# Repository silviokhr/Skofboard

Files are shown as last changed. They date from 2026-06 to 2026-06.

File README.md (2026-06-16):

# Split Ergonomic Wireless Gasket-Mounted Keyboard

<div align="center">
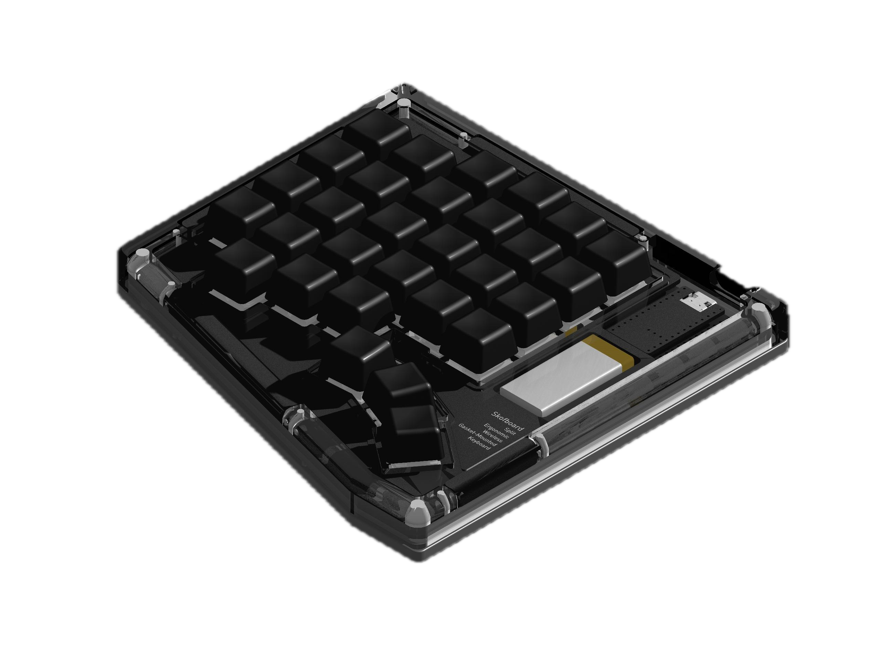
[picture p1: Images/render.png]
Split Ergonomic Keyboard
  
</div>

## Features

- **Ergonomic split design** — reduces wrist strain and promotes a more neutral typing position
- **Ortholinear layout**     — aligns keys in a grid, reducing finger travel distance with 3 dedicated thumb buttons
- **Gasket-mounted PCB**     — provides a dampened sound profile and soft keystroke feel
- **Magnetic closure**       — enables quick assembly and disassembly without tools
- **Reversible PCB design**  — single PCB works for both left and right halves
- **Hot-swappable switches** — easily swap or customize switches without soldering
- **ZMK firmware support**   — fully customizable keymap via ZMK Studio
- **Wireless connectivity**  — powered by the nice!nano v2.0 microcontroller

---

## Case

All case parts are CNC machined, and material selection significantly impacts the sound profile. The rigid aluminum base dampens resonance while the polycarbonate top provides acoustic transparency, and rounded internal surfaces minimize harsh reflections for a refined keystroke sound. STL files are included for 3D-printed case variants.

| Part | Material | Surface Finish |
|---|---|---|
| Top casing | Polycarbonate (PC) | Blue-tinted vapor polishing |
| Bottom casing | Aluminum 6061 | Bead blasting + anodizing |

---

## Parts List (Bill of Materials)

Quantities are **per half** — a complete keyboard requires two of everything below.

| Qty | Component | Specification |
|-----|---|---|
| 8 | Corner magnet | Neodymium disc, ⌀4 × 3 mm |
| 16 | Edge magnet | Neodymium disc, ⌀2 × 3 mm |
| 6 | Large gasket foam | Poron, 4.5 × 7 × 2 mm |
| 2 | Small gasket foam | Poron, 4.5 × 4 × 2 mm |
| 4 | Rubber foot | ⌀8 × 1.6 mm |
| 1 | Microcontroller | nice!nano v2.0 |
| 2 | Microcontroller socket 12-pin | Mill Max 315-43-112-41-003000 |
| 24 | Socket pins | Mill Max 3320-0-00-15-00-00-03-0 |
| 1 | Battery | 3.7 V LiPo, 250 mAh, model 502030, 2P-PH connector |
| 1 | Battery connector | S2B-PH-K-S(LF)(SN) |
| 1 | Power switch | MSK12C02 (SMD slide switch) |
| 30 | Keyswitch | MX-format (any compatible switch) |
| 30 | Hotswap socket | Kailh MX-format |
| 30 | Diode | 1N4148W, SOD-123 |

### Part Notes

Only the parts below have constraints or behavior worth calling out; everything else fits as listed.

- **Magnets** — Cutouts are intentionally oversized to ensure a proper fit during assembly. Corner cutouts are ⌀4.1 mm × 3 mm deep; edge cutouts are ⌀2.1 mm × 3 mm deep.
- **Rubber feet** — Seat into ⌀8 mm × 1.5 mm-deep cutouts and must protrude a minimum of 0.1 mm below the case bottom for optimal grip.
- **Battery** — The cutout on the top plate is shared with the battery connector jack, which limits usable space. Optimal dimensions are **50 mm (H) × 20 mm (W) × 30 mm (D)**. ⚠️ Taller batteries are possible, but wider or longer batteries are not recommended and may not fit reliably.

---

## PCB Specifications

- **Layer count:** 2-layer
- **Material:** FR-4, 1.6 mm thickness
- **Copper weight:** 1 oz
- **Surface finish:** LeadFree HASL

**Design note:** The PCB switchplate (`SkofTopPlate.kicad_pcb`) is 1.6 mm FR-4 (standard manufacturing thickness), while standard MX switches are designed for 1.5 mm plates. Because of this 0.1 mm difference, switches fit securely but may feel slightly tight.

---

## Keymap

The default keymap is currently a placeholder and varies by region. To customize it, press the **`studio_unlock`** key on the left half — at **column 1, row 2** — to enter configuration mode in ZMK Studio.

---

## Assembly Guide

> Build is **per half** — repeat all steps for both. The PCB is reversible, so each half is configured by solder jumpers (step 3) before anything is populated.

**Case prep**

1. **Attach the feet** to the bottom casing.
2. **Glue in the magnets** (corner and edge) into their cutouts. ⚠️ Check polarity *before* gluing — all magnets must be oriented so the top and bottom casings attract when closed. (See Part Notes for fit.)

**PCB**

3. **Set the handedness** — close the solder-jumper bridges that configure the PCB for the left or right half (per the build files), **before** soldering any sockets:
   - **Microcontroller** jumpers — front (top) side
   - **Battery** jumpers — back (bottom) side
4. **Populate the PCB** — on the **back**, solder the diodes and hotswap sockets; on the **front**, solder the power switch, battery connector, and microcontroller sockets.
5. **Mount the nice!nano v2.0** — seat the header pins in the sockets, then mount the controller **face-down (component side against the PCB, bare back facing up)** and solder the pins so it stays removable.

**Power test** *(before switches — easier to fix solder issues now)*

6. **Connect the battery** with the power switch **off**, checking polarity.
7. **Flash and test** — flash the firmware (double-tap reset for the bootloader), power on, and confirm the half boots, pairs with the other half, and connects to your host.

**Plate + switches**

8. **Add the gasket foam** — place the foam strips in their positions per the build files.
9. **Install switches** — straighten any bent pins, fit 3–4 corner switches first to align the plate, then drop in the rest through the switchplate.

**Finish**

10. **Final check** — verify every key registers.
11. **Close the case** — join the top and bottom casings via the magnetic closure.

---

## Credits

This project uses open-source hardware footprints licensed under MIT and CC-BY-NC-SA 4.0 by Marco Massarelli (@ceoloide) and contributors.

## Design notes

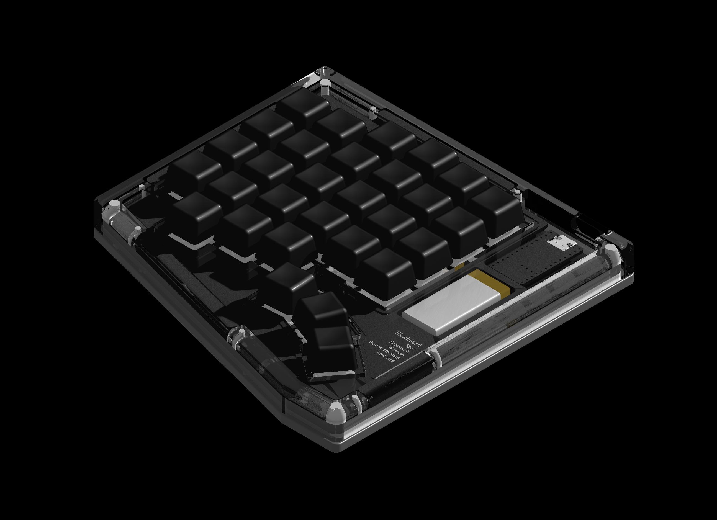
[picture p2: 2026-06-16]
Images/render.jpeg

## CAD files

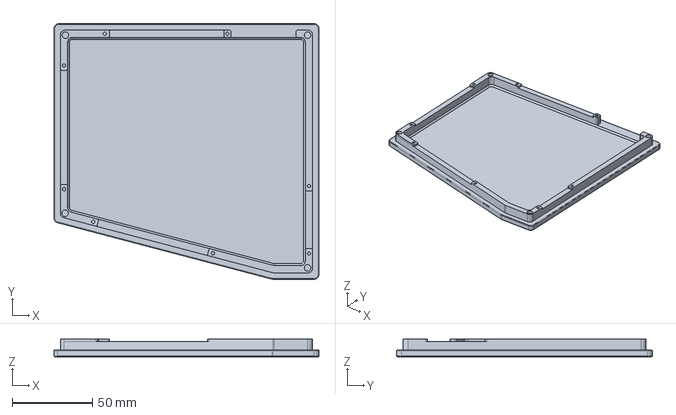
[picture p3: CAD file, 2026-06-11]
Case/Left/Bottom/BB6_BOT_L.stp
164.9 x 159.0 x 10.9 mm

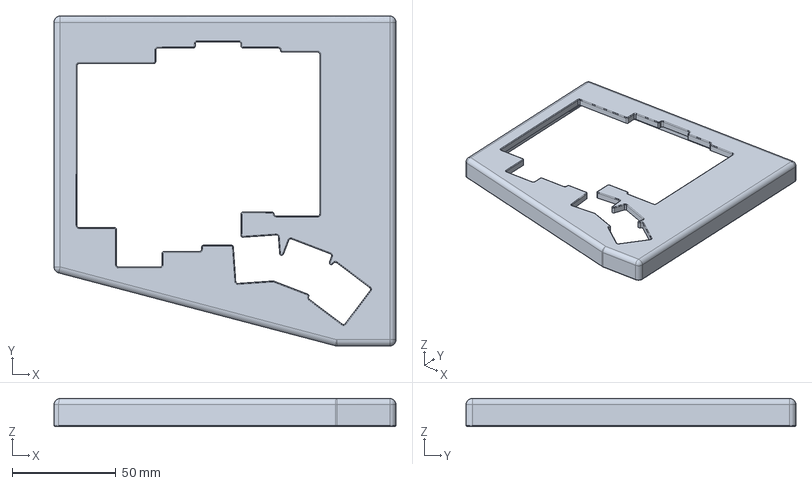
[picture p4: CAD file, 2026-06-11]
Case/Left/Top/BB5_TOP_L.stp
164.9 x 159.0 x 13.5 mm

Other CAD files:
Case/Right/Bottom/BB6_BOT_R.stp
Case/Right/Top/BB5_TOP_R.stp
Case/Left/Bottom/BB6_BOT_L.stl
Case/Left/Top/BB5_TOP_L.stl
Case/Right/Bottom/BB6_BOT_R.stl
Case/Right/Top/BB5_TOP_R.stl

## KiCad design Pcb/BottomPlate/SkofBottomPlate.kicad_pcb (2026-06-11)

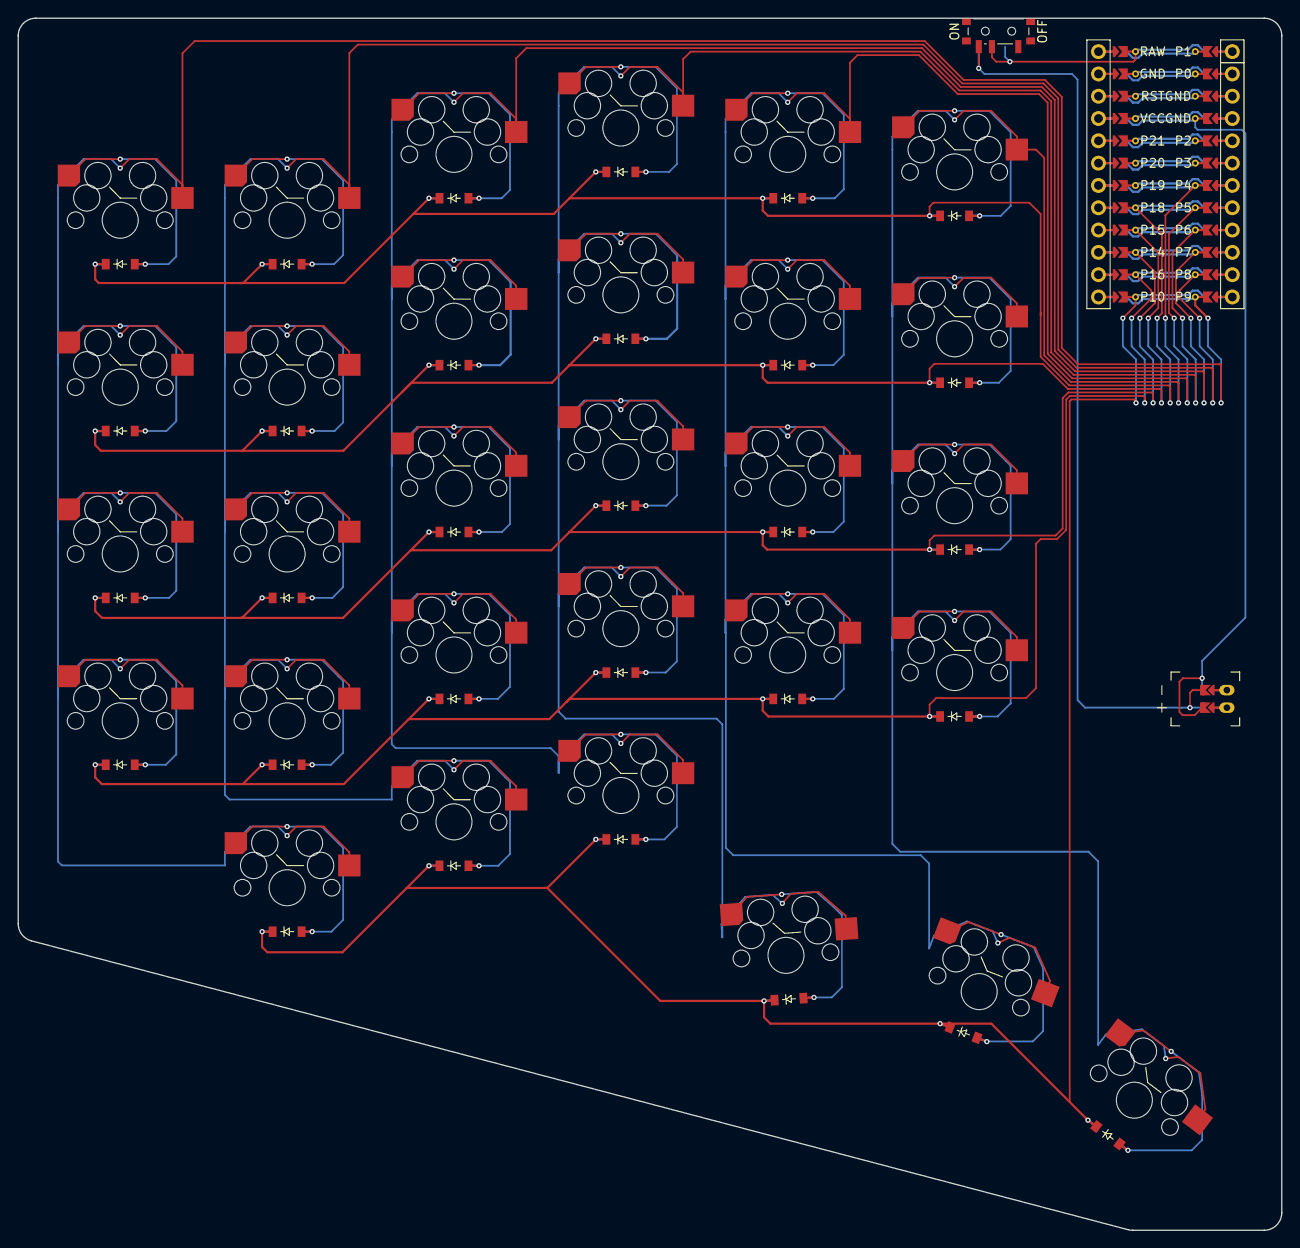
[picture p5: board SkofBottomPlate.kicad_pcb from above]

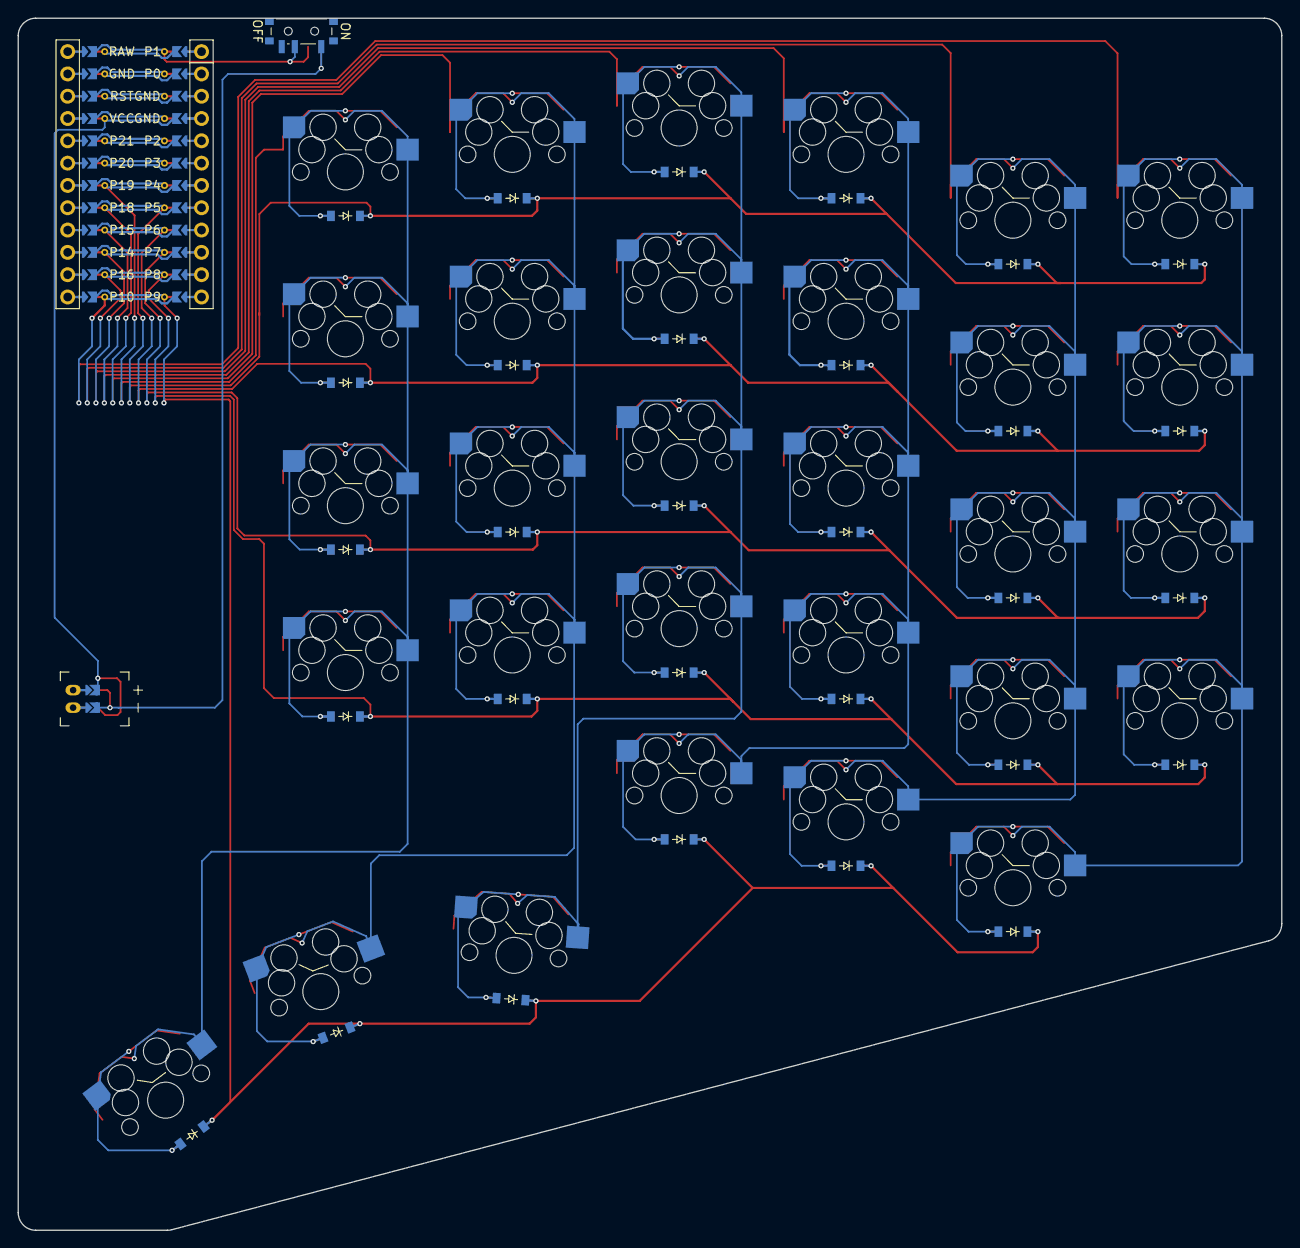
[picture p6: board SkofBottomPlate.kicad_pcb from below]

Board: 2 copper layers, 143.9 x 138.0 mm, 63 parts (30 on the bottom side), 46 nets.

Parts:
D1, D2, D3, D4, D5, D6, D7, D8, D9, D10, D11, D12, D13, D14, D15, D16, D17, D18, D19, D20, D21, D22, D23, D24, D25, D26, D27, D28, D29, D30: diode_tht_sod123
JST1: battery_connector_jst_ph_2
MCU1: mcu_nice_nano
PWR1: power_switch_smd_side
S1, S2, S3, S4, S5, S6, S7, S8, S9, S10, S11, S12, S13, S14, S15, S16, S17, S18, S19, S20, S21, S22, S23, S24, S25, S26, S27, S28, S29, S30: switch_mx

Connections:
BAT_P: JST1.1, PWR1.1, PWR1.3
GND: JST1.2, MCU1.103, MCU1.104, MCU1.123
JST1_1: JST1.11, JST1.21, JST1.31
JST1_2: JST1.12, JST1.22, JST1.32
P4: MCU1.107, S24.1, S25.1, S26.1, S27.1, S30.1
P5: MCU1.108, S20.1, S21.1, S22.1, S23.1, S29.1
P6: MCU1.109, S16.1, S17.1, S18.1, S19.1, S28.1
P7: MCU1.110, S11.1, S12.1, S13.1, S14.1, S15.1
P8: MCU1.111, S6.1, S7.1, S8.1, S9.1, S10.1
P9: MCU1.112, S1.1, S2.1, S3.1, S4.1, S5.1
P10: D5.1, D10.1, D15.1, D28.1, D29.1, D30.1, MCU1.113
P14: D2.1, D7.1, D12.1, D17.1, D21.1, D25.1, MCU1.115
P15: D3.1, D8.1, D13.1, D18.1, D22.1, D26.1, MCU1.116
P16: D1.1, D6.1, D11.1, D16.1, D20.1, D24.1, MCU1.114
P18: D4.1, D9.1, D14.1, D19.1, D23.1, D27.1, MCU1.117
RAW: MCU1.124, PWR1.2
filler_cluster: D28.2, S28.2
index_home: D20.2, S20.2
index_num: D22.2, S22.2
index_nums: D23.2, S23.2
index_top: D21.2, S21.2
inner_home: D24.2, S24.2
inner_num: D26.2, S26.2
inner_nums: D27.2, S27.2
inner_top: D25.2, S25.2
layer_cluster: D29.2, S29.2
middle_bottom: D15.2, S15.2
middle_home: D16.2, S16.2
middle_num: D18.2, S18.2
middle_nums: D19.2, S19.2
middle_top: D17.2, S17.2
outer_home: D1.2, S1.2
outer_num: D3.2, S3.2
outer_nums: D4.2, S4.2
outer_top: D2.2, S2.2
pinky_bottom: D5.2, S5.2
pinky_home: D6.2, S6.2
pinky_num: D8.2, S8.2
pinky_nums: D9.2, S9.2
pinky_top: D7.2, S7.2
ring_bottom: D10.2, S10.2
ring_home: D11.2, S11.2
ring_num: D13.2, S13.2
ring_nums: D14.2, S14.2
ring_top: D12.2, S12.2
space_cluster: D30.2, S30.2
